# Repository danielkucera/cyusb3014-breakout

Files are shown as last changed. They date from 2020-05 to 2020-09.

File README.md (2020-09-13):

View this project on [CADLAB.io](https://cadlab.io/project/23305). 

# Cypress FX3 CYUSB3014 breakout board

## Hardware

This design is a copy of QM Tech board: https://github.com/ChinaQMTECH/QM_CYUSB3014_USB3.0

You can find the most recent schematic in releases https://github.com/danielkucera/cyusb3014-breakout/releases

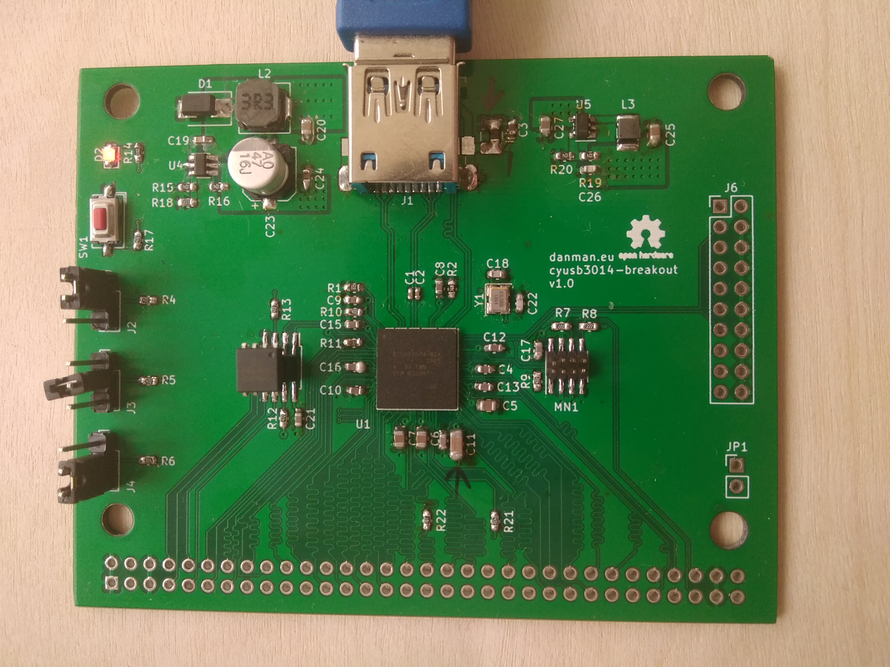
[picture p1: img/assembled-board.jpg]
assembled-board


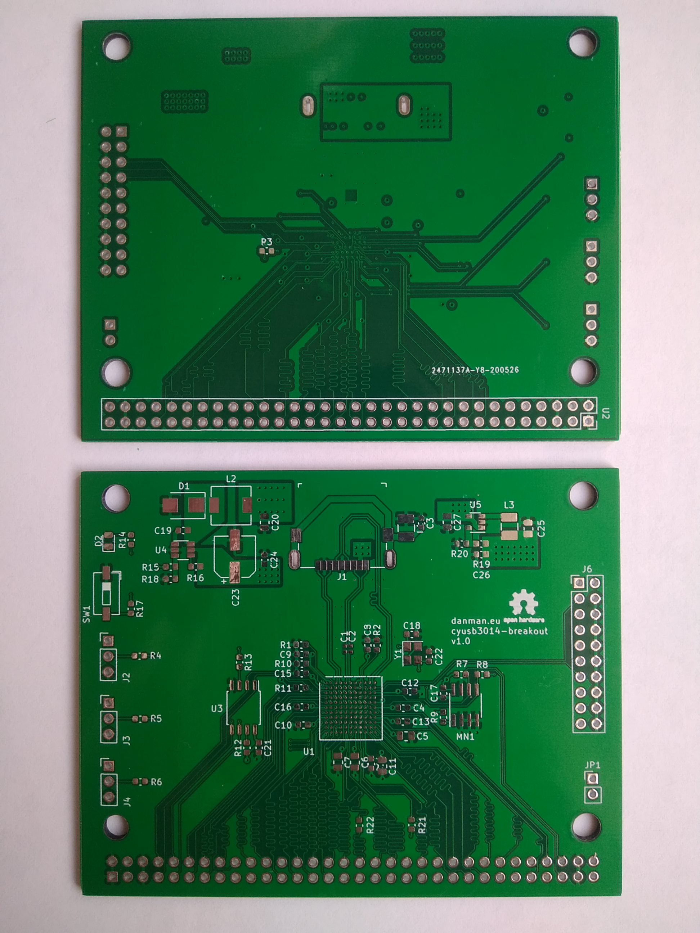
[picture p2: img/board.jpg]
board


## Software

For quick testing of the board you can use the SPI image and python script from folder [software](/software)

These are my results for bulk loop test:

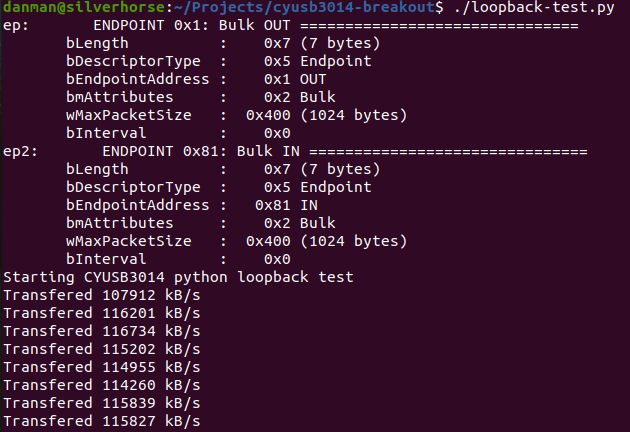
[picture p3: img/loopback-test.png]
test-results


## I want one

Contact me in some way, I have some spare boards, I can send you a bare board or an assembled one for some small donation.

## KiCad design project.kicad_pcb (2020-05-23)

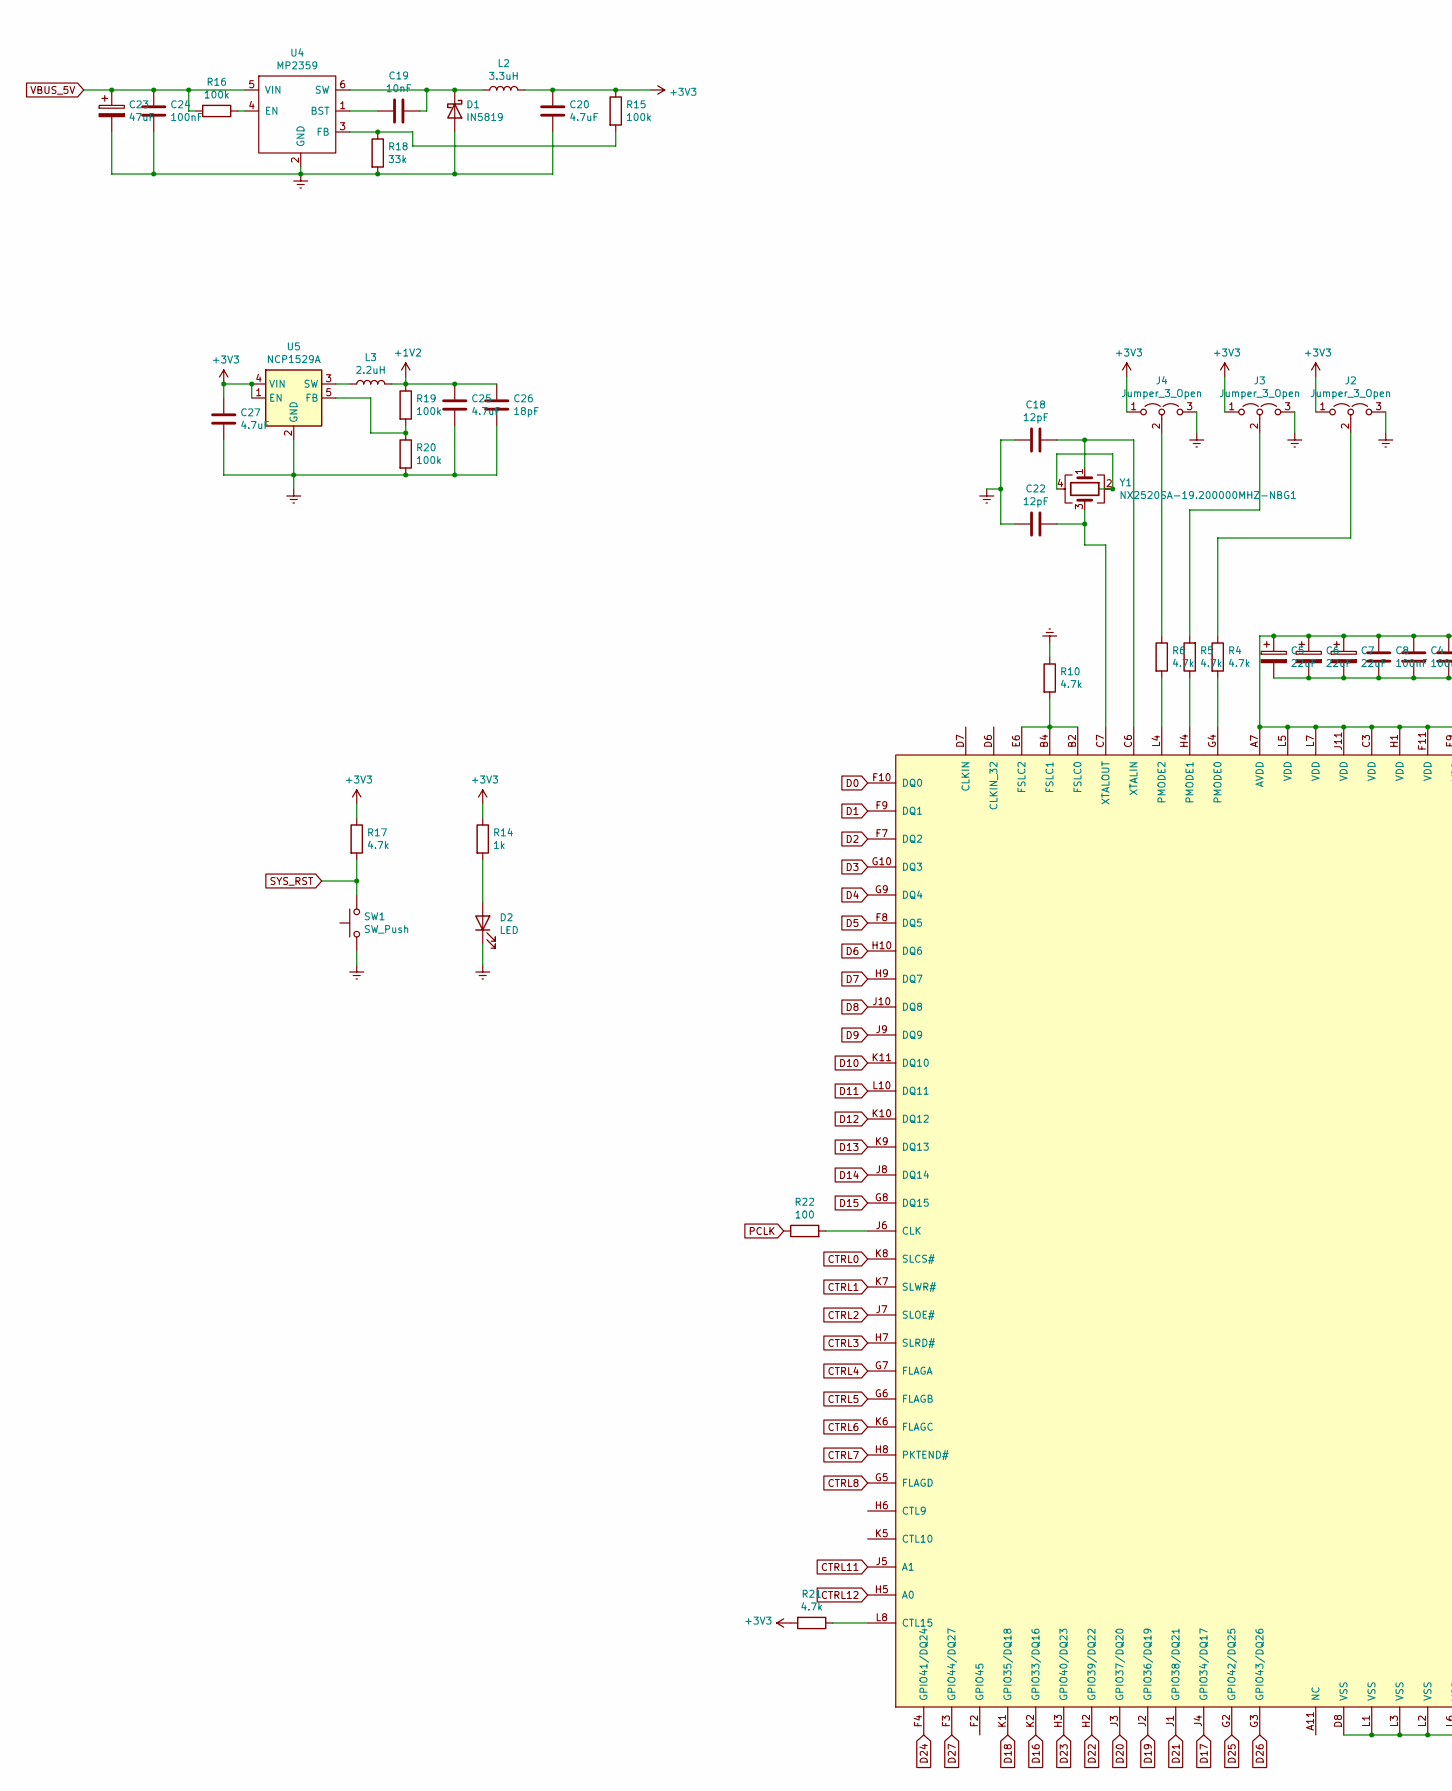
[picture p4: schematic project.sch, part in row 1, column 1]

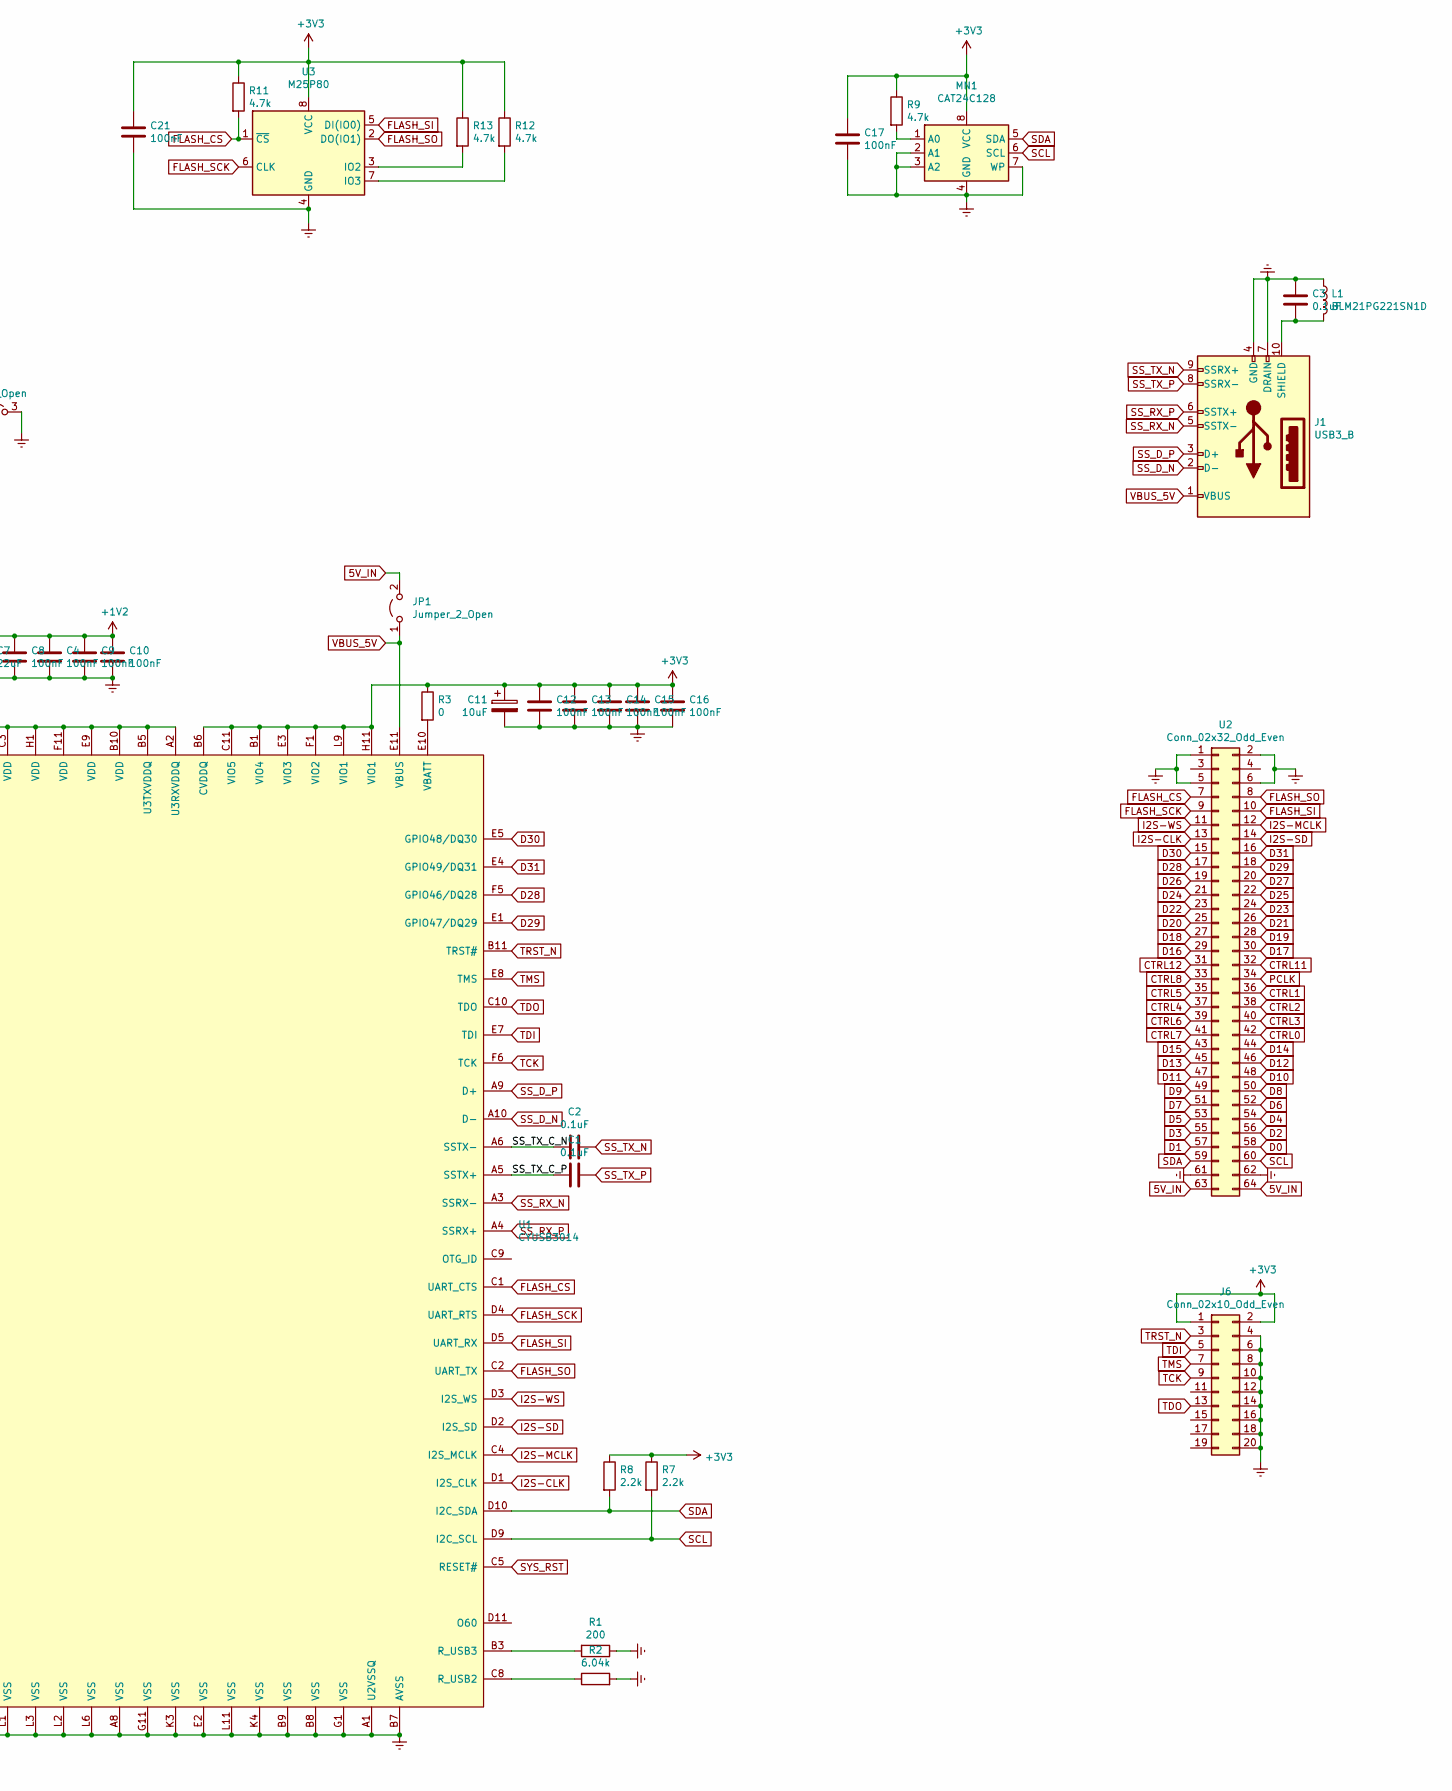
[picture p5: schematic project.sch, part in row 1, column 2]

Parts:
C1, C2: 0.1uF; C_0402_1005Metric
C3: 0.1uF; C_0603_1608Metric
C4, C8, C9, C10, C12, C13, C14, C15, C16, C17, C21, C24: 100nF; C_0603_1608Metric
C5, C6, C7: 22uF; C_0805_2012Metric
C11: 10uF; C_0805_2012Metric
C18, C22: 12pF; C_0603_1608Metric
C19: 10nF; C_0603_1608Metric
C20, C25, C27: 4.7uF; C_0805_2012Metric
C23: 47uF; CP_Elec_6.3x5.8
C26: 18pF; C_0603_1608Metric
D1: IN5819; D_SMB
D2: LED; LED_0805_2012Metric
J1: USB3_B; USB_A_Female_AU-Y1006-3
J2, J3, J4: Jumper_3_Open; PinHeader_1x03_P2.54mm_Vertical
J6: Conn_02x10_Odd_Even; PinHeader_2x10_P2.54mm_Vertical
JP1: Jumper_2_Open; PinHeader_1x02_P2.54mm_Vertical
L1: BLM21PG221SN1D; L_1210_3225Metric_Pad1.42x2.65mm_HandSolder
L2: 3.3uH; L_6.3x6.3_H3
L3: 2.2uH; L_1210_3225Metric_Pad1.42x2.65mm_HandSolder
MN1: CAT24C128; SOIC-8_3.9x4.9mm_P1.27mm
R1: 200; R_0603_1608Metric
R2: 6.04k; R_0603_1608Metric
R3: 0; R_0603_1608Metric
R4, R5, R6, R9, R10, R11, R12, R13, R17, R21: 4.7k; R_0603_1608Metric
R7, R8: 2.2k; R_0603_1608Metric
R14: 1k; R_0603_1608Metric
R15, R16, R19, R20: 100k; R_0603_1608Metric
R18: 33k; R_0603_1608Metric
R22: 100; R_0603_1608Metric
SW1: SW_Push; SW_DIP_SPSTx01_Slide_6.7x4.1mm_W6.73mm_P2.54mm_LowProfile_J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
U1: CYUSB3014; TFBGA-121_10x10mm_Layout11x11_P0.8mm; Voltage _; Tolerance _
U2: Conn_02x32_Odd_Even; PinSocket_2x32_P2.54mm_Vertical
U3: M25P80; SOIC-8_5.23x5.23mm_P1.27mm
U4: MP2359; TSOT-23-6
U5: NCP1529A; SOT-23-5
Y1: NX2520SA-19.200000MHZ-NBG1; Crystal_SMD_3225-4Pin_3.2x2.5mm

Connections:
5V_IN: JP1.2 (B), U2.63, U2.64
+1V2: C4.1, C5.1, C6.1, C7.1, C8.1, C9.1, C10.1, C25.1, C26.1, L3.2, R19.1, U1.A2 (U3RXVDDQ), U1.A7 (AVDD), U1.B5 (U3TXVDDQ), U1.B10 (VDD), U1.C3 (VDD), U1.E9 (VDD), U1.F11 (VDD), U1.H1 (VDD), U1.J11 (VDD), U1.L5 (VDD), U1.L7 (VDD)
+3V3: C11.1, C12.1, C13.1, C14.1, C15.1, C16.1, C17.1, C20.1, C21.1, C27.1, J2.1 (A), J3.1 (A), J4.1 (A), J6.1, J6.2, L2.2, MN1.8 (VCC), R3.1, R7.1, R8.1, R9.1, R11.1, R12.1, R13.1, R14.1, R15.1, R17.1, R21.2, U1.B1 (VIO4), U1.B6 (CVDDQ), U1.C11 (VIO5), U1.E3 (VIO3), U1.F1 (VIO2), U1.H11 (VIO1), U1.L9 (VIO1), U3.8 (VCC), U5.1 (EN), U5.4 (VIN)
/SS_TX_C_N: C2.1, U1.A6 (SSTX-)
/SS_TX_C_P: C1.2, U1.A5 (SSTX+)
CTRL0: U1.K8 (SLCS#), U2.42
CTRL1: U1.K7 (SLWR#), U2.36
CTRL2: U1.J7 (SLOE#), U2.38
CTRL3: U1.H7 (SLRD#), U2.40
CTRL4: U1.G7 (FLAGA), U2.37
CTRL5: U1.G6 (FLAGB), U2.35
CTRL6: U1.K6 (FLAGC), U2.39
CTRL7: U1.H8 (PKTEND#), U2.41
CTRL8: U1.G5 (FLAGD), U2.33
CTRL11: U1.J5 (A1), U2.32
CTRL12: U1.H5 (A0), U2.31
D0: U1.F10 (DQ0), U2.58
D1: U1.F9 (DQ1), U2.57
D2: U1.F7 (DQ2), U2.56
D3: U1.G10 (DQ3), U2.55
D4: U1.G9 (DQ4), U2.54
D5: U1.F8 (DQ5), U2.53
D6: U1.H10 (DQ6), U2.52
D7: U1.H9 (DQ7), U2.51
D8: U1.J10 (DQ8), U2.50
D9: U1.J9 (DQ9), U2.49
D10: U1.K11 (DQ10), U2.48
D11: U1.L10 (DQ11), U2.47
D12: U1.K10 (DQ12), U2.46
D13: U1.K9 (DQ13), U2.45
D14: U1.J8 (DQ14), U2.44
D15: U1.G8 (DQ15), U2.43
D16: U1.K2 (GPIO33/DQ16), U2.29
D17: U1.J4 (GPIO34/DQ17), U2.30
D18: U1.K1 (GPIO35/DQ18), U2.27
D19: U1.J2 (GPIO36/DQ19), U2.28
D20: U1.J3 (GPIO37/DQ20), U2.25
D21: U1.J1 (GPIO38/DQ21), U2.26
D22: U1.H2 (GPIO39/DQ22), U2.23
D23: U1.H3 (GPIO40/DQ23), U2.24
D24: U1.F4 (GPIO41/DQ24), U2.21
D25: U1.G2 (GPIO42/DQ25), U2.22
D26: U1.G3 (GPIO43/DQ26), U2.19
D27: U1.F3 (GPIO44/DQ27), U2.20
D28: U1.F5 (GPIO46/DQ28), U2.17
D29: U1.E1 (GPIO47/DQ29), U2.18
D30: U1.E5 (GPIO48/DQ30), U2.15
D31: U1.E4 (GPIO49/DQ31), U2.16
Earth: C3.1, C4.2, C5.2, C6.2, C7.2, C8.2, C9.2, C10.2, C11.2, C12.2, C13.2, C14.2, C15.2, C16.2, C17.2, C18.2, C20.2, C21.2, C22.2, C23.2, C24.2, C25.2, C26.2, C27.2, D1.2 (A), D2.1 (K), J1.4 (GND), J1.7 (DRAIN), J2.3 (B), J3.3 (B), J4.3 (B), J6.4, J6.6, J6.8, J6.10, J6.12, J6.14, J6.16, J6.18, J6.20, L1.1, MN1.2 (A1), MN1.3 (A2), MN1.4 (GND), MN1.7 (WP), R1.1, R2.2, R10.1, R18.2, R20.2, SW1.1, U1.A1 (U2VSSQ), U1.A8 (VSS), U1.B7 (AVSS), U1.B8 (VSS), U1.B9 (VSS), U1.D8 (VSS), U1.E2 (VSS), U1.G1 (VSS), U1.G11 (VSS), U1.K3 (VSS), U1.K4 (VSS), U1.L1 (VSS), U1.L2 (VSS), U1.L3 (VSS), U1.L6 (VSS), U1.L11 (VSS), U2.1, U2.2, U2.5, U2.6, U2.61, U2.62, U3.4 (GND), U4.2 (GND), U5.2 (GND)
FLASH_CS: R11.2, U1.C1 (UART_CTS), U2.7, U3.1 (~CS)
FLASH_SCK: U1.D4 (UART_RTS), U2.9, U3.6 (CLK)
FLASH_SI: U1.D5 (UART_RX), U2.10, U3.5 (DI(IO0))
FLASH_SO: U1.C2 (UART_TX), U2.8, U3.2 (DO(IO1))
I2S-CLK: U1.D1 (I2S_CLK), U2.13
I2S-MCLK: U1.C4 (I2S_MCLK), U2.12
I2S-SD: U1.D2 (I2S_SD), U2.14
I2S-WS: U1.D3 (I2S_WS), U2.11
unnamed: C3.2, J1.10 (SHIELD), L1.2
unnamed: C18.1, U1.C6 (XTALIN), Y1.1
unnamed: C19.1, D1.1 (K), L2.1, U4.6 (SW)
unnamed: C19.2, U4.1 (BST)
unnamed: C22.1, U1.C7 (XTALOUT), Y1.3
unnamed: D2.2 (A), R14.2
unnamed: J2.2 (C), R4.1
unnamed: J3.2 (C), R5.2
unnamed: J4.2 (C), R6.1
unnamed: L3.1, U5.3 (SW)
unnamed: MN1.1 (A0), R9.2
unnamed: R1.2, U1.B3 (R_USB3)
unnamed: R2.1, U1.C8 (R_USB2)
unnamed: R3.2, U1.E10 (VBATT)
unnamed: R4.2, U1.G4 (PMODE0)
unnamed: R5.1, U1.H4 (PMODE1)
unnamed: R6.2, U1.L4 (PMODE2)
unnamed: R10.2, U1.B2 (FSLC0), U1.B4 (FSLC1), U1.E6 (FSLC2)
unnamed: R12.2, U3.7 (IO3)
unnamed: R13.2, U3.3 (IO2)
unnamed: R15.2, R18.1, U4.3 (FB)
unnamed: R16.1, U4.4 (EN)
unnamed: R19.2, R20.1, U5.5 (FB)
unnamed: R21.1, U1.L8 (CTL15)
unnamed: R22.2, U1.J6 (CLK)
unnamed: Y1.2, Y1.4
PCLK: R22.1, U2.34
SCL: MN1.6 (SCL), R7.2, U1.D9 (I2C_SCL), U2.60
SDA: MN1.5 (SDA), R8.2, U1.D10 (I2C_SDA), U2.59
SS_D_N: J1.2 (D-), U1.A10 (D-)
SS_D_P: J1.3 (D+), U1.A9 (D+)
SS_RX_N: J1.5 (SSTX-), U1.A3 (SSRX-)
SS_RX_P: J1.6 (SSTX+), U1.A4 (SSRX+)
SS_TX_N: C2.2, J1.9 (SSRX+)
SS_TX_P: C1.1, J1.8 (SSRX-)
SYS_RST: R17.2, SW1.2, U1.C5 (RESET#)
TCK: J6.9, U1.F6 (TCK)
TDI: J6.5, U1.E7 (TDI)
TDO: J6.13, U1.C10 (TDO)
TMS: J6.7, U1.E8 (TMS)
TRST_N: J6.3, U1.B11 (TRST#)
VBUS_5V: C23.1, C24.1, J1.1 (VBUS), JP1.1 (A), R16.2, U1.E11 (VBUS), U4.5 (VIN)

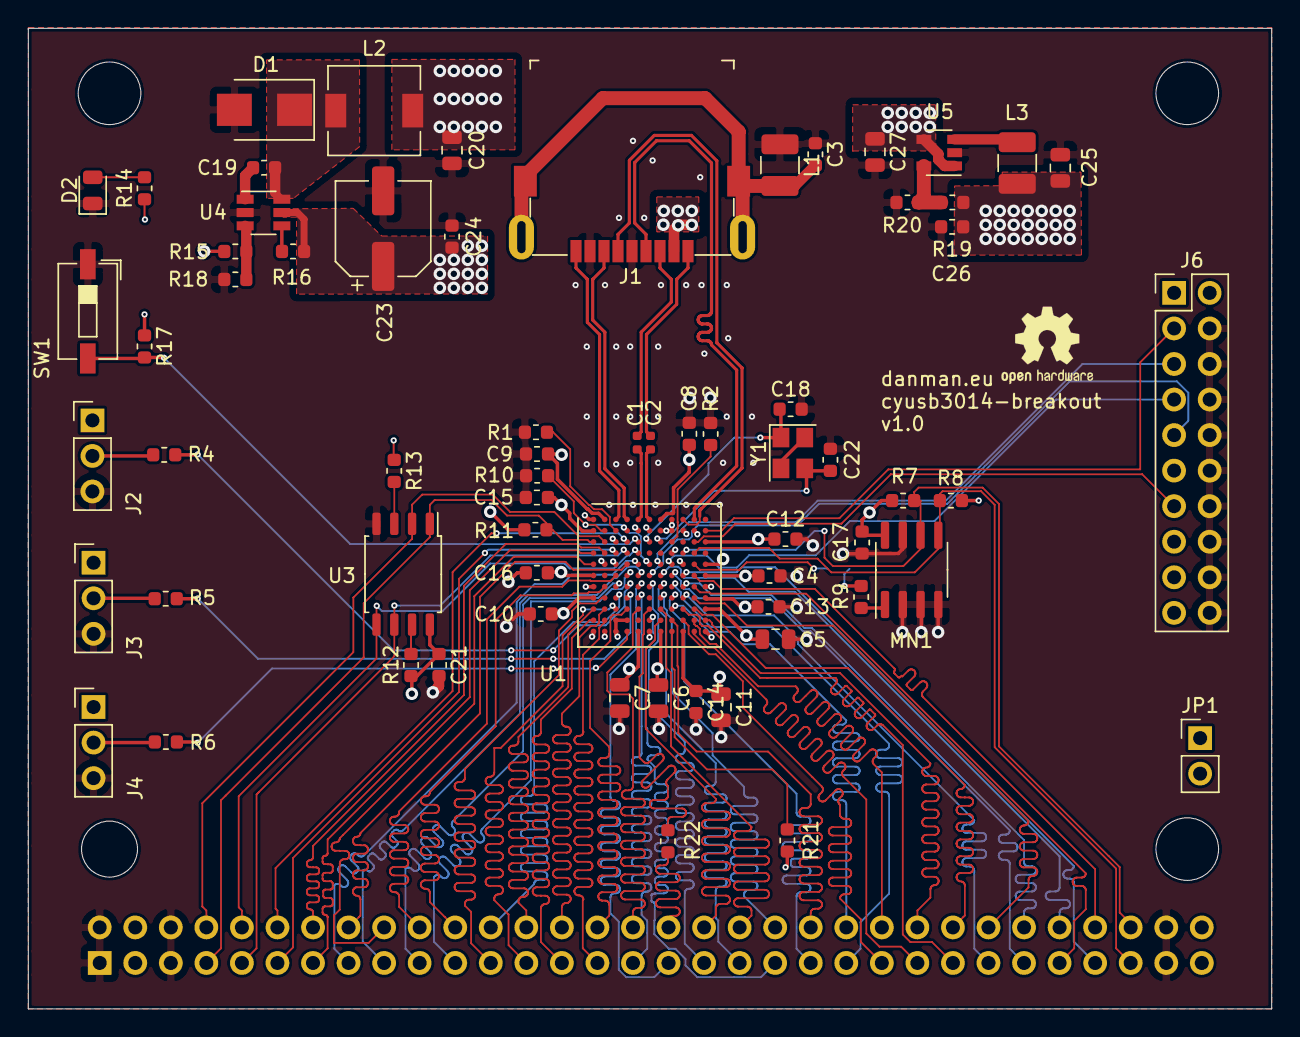
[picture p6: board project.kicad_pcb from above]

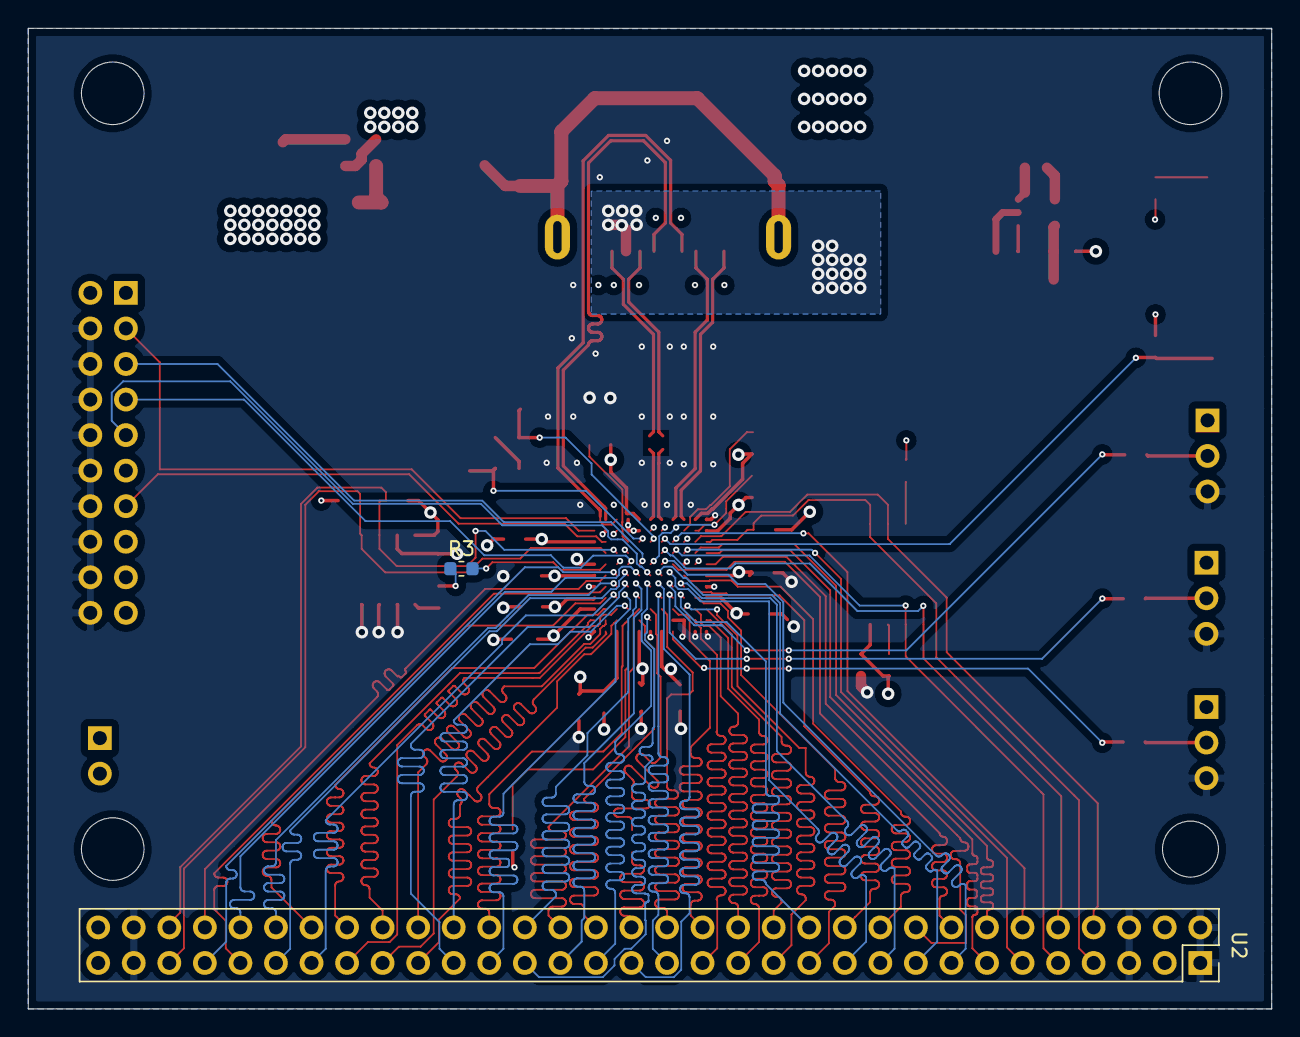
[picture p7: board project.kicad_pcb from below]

Board: 4 copper layers, 88.8 x 70.1 mm, 68 parts (2 on the bottom side), 99 nets.

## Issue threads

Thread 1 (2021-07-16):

Quick fix for Python3

mcuee, 2021-07-16:
I just made a simple fix here to get the python code working under Python 3.
https://github.com/mcuee/python_usb/blob/master/cyusb_fx3_loopback-test_python3.py

mcuee, 2021-07-16:
BTW, I also use your codes to create a new code to test the BulkSrcSink FW.
https://github.com/mcuee/python_usb/blob/master/cyusb_fx3_sourcesink_python3.py

danielkucera, 2021-07-16:
yes, the obvious `print()` ... what is the difference between `thread` and `_thread` ?

mcuee, 2021-07-16:
Not a python expert but I found the following.
https://stackoverflow.com/questions/36809788/importerror-no-module-named-thread
In Python 3 instead of:
```
import thread
```
Do:
```
import _thread
```

mcuee, 2021-07-16:
Maybe the better fix is to use threading module.
https://www.tutorialspoint.com/python3/python_multithreading.htm

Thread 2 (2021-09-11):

Why the capacitors between SSTX on the chip and SSRX on the connector?

taktoa, 2021-09-11:
As the title asks, why did you add 0.1uF capacitors between SSTX on the chip and SSRX on the connector? Also, why did you swap SSTX+ and SSTX-? Was this just to make the routing easier? Does it have any impact on maximum data rate?

danielkucera, 2021-09-12:
Hi @taktoa , I was making changes strictly with accordance to with the [Hardware Design Guidelines](https://www.cypress.com/file/139936/download) , section 12.1
Capacitors are a must for this chip.
You can swap + and - in USB3 differential pairs if it makes your routing easier.

taktoa, 2021-09-12:
Thanks, that helps

Closed 2021-09-12.

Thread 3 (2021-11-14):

BGA pads and vias

mgiacomelli, 2021-11-14:
I was looking through this design to see how hard a layout would be using the FX3 and I noticed you have the BGA pads touching the vias with no solder mask between them.  Did you need to fill the vias with something before reflow?  Most of the advice I found online says not to put the vias under BGA balls due to wicking, although I suppose with very small (0.2mm) maybe this is less of an issue.

danielkucera, 2021-11-14:
There is solder mask on vias. I didn't do anything special before the reflow.

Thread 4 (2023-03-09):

CYUSB3014 consulting

dmikushin, 2023-03-09:
Hey @danielkucera ,

Great work on CYUSB3014 board! A startup pursuer here, in the field of high-performance eyetracking! We are looking for someone who could dedicate us some time to answer our rather basic questions about this SoC. For example, we are wondering what flavor of U-boot could we flash on the board, in order to have our own bootloader on CYUSB3014 with features that we want.

Looking forward to getting in touch with you!

Kind regards,
- Dmitry.

danielkucera, 2023-03-09:
Hi Dmitry,
I am afraid I cannot help you. I ended with some basic tests on the chip, noting more.

dmikushin, 2023-03-09:
That's a pity. Could you still sell us some assembled dev boards? Unfortunately, QMTech does not sell them any more.

danielkucera, 2023-03-09:
I have one assembled and a few bare PCBs. We can make a deal. Contact me through blog.danman.eu contact form.

dmikushin, 2023-03-09:
> Contact me through blog.danman.eu contact form.

Yes I've tried it first, but it gives "try again" error.

mgiacomelli, 2023-03-10:
You can also buy the Cypress development boards relatively inexpensively.  The software stack they provide is flexible, and you can recompile a lot of it to customize for each application.  For example I went through and rearranged it in memory to free up more SRAM for my image acquisition app.

danielkucera, 2023-03-10:
@dmikushin , please try again, I have fixed the error.

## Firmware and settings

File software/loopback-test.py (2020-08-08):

#!/usr/bin/python

import usb.core
import usb.util
import time
import thread

# find our device
dev = usb.core.find(idVendor=0x04b4, idProduct=0x00f0 )

# was it found?
if dev is None:
    raise ValueError('Device not found')

# set the active configuration. With no arguments, the first
# configuration will be the active one
dev.set_configuration()

# get an endpoint instance
cfg = dev.get_active_configuration()

#intf = cfg[(0,1)]

#dev.set_interface_altsetting(interface = 0, alternate_setting = 0)
intf = cfg[(0,0)]

#print intf

ep = usb.util.find_descriptor(
    intf,
    # match the first OUT endpoint
    custom_match = \
    lambda e: \
        e.bEndpointAddress == 1)

ep2 = usb.util.find_descriptor(
    intf,
    # match the first OUT endpoint
    custom_match = \
    lambda e: \
        e.bEndpointAddress == 0x81)

assert ep is not None
assert ep2 is not None

print 'ep:',ep
print 'ep2:',ep2

chunkr = 2**16
chunkw = 2**22

print "Starting CYUSB3014 python loopback test"

def read_loop():
    start = time.time()
    trans = 0
    while True:
        data = dev.read(0x81, chunkw, 1000)
        trans = trans + len(data)
        if time.time() > start + 1:
            bps = trans/(time.time() - start)
            print ("Transfered %d kB/s" % (bps/(1024)) )
            trans = 0
            start = time.time()

def write_loop():
    dat = "A"*chunkw
    while True:
        try:
            ep.write(dat)
        except:
            pass

thread.start_new_thread( write_loop, () )

read_loop()

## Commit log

2020-05-21 initial commit - top layer routed
    [project.kicad_pcb, project.sch]
2020-05-23 everything routed
    [project.kicad_pcb, project.sch]
2020-05-23 final with silk and holes
    [project.kicad_pcb]
2020-05-23 5v on pwr plane
    [project.kicad_pcb]
2020-05-23 added logo
    [project.kicad_pcb]
2020-06-13 added manufactured board photo
2020-08-08 added loop image from cypress samples
